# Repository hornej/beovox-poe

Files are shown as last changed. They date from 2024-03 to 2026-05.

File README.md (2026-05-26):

# BeoVox PoE

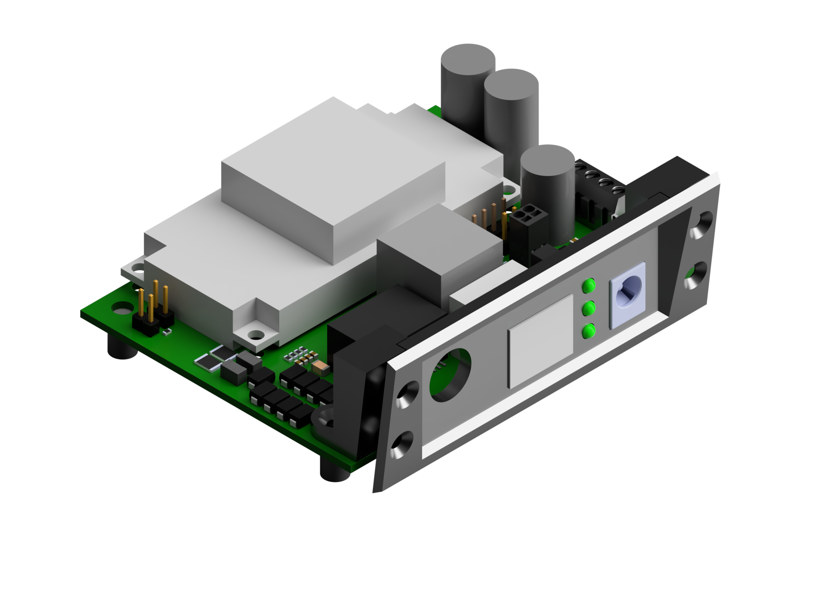
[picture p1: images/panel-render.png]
Panel mount render


BeoVox PoE is an 80 W PoE-PD power board and panel-mount system for installing a Raspberry Pi and a [HiFiBerry Beocreate amplifier](https://www.hifiberry.com/shop/boards/beocreate-4-channel-amplifier/) inside Bang & Olufsen BeoVox CX50 or CX100 speakers.

The design takes in PoE power, passes Ethernet data through to the Raspberry Pi, and gives you a single-cable install for a network-connected speaker build. HiFiBerryOS supports streaming music via Bluetooth, Airplay, Spotify, Roon, and more. 
## Table of Contents

- [Features](#features)
- [Repository Layout](#repository-layout)
- [Guides](#guides)
- [Photos](#photos)
- [Parts List](#parts-list)
- [PCB](#pcb)
  - [PCB Specs and Ordering](#pcb-specs-and-ordering)
  - [PCB Setup and Notes](#pcb-setup-and-notes)
  - [Soldering](#soldering)
  - [Jumper Headers](#jumper-headers)
  - [Optional Connections](#optional-connections)
- [Panel Mount](#panel-mount)
  - [3D Printing](#3d-printing)
  - [Rear Panel Opening](#rear-panel-opening)
  - [Panel Assembly](#panel-assembly)
- [Wiring](#wiring)
  - [CX50](#cx50)
  - [CX100](#cx100)
  - [CX100 with switchable subwoofer](#cx100-with-switchable-subwoofer)
- [Software Setup](#software-setup)
- [Future Work / Ideas](#future-work--ideas)
- [License](#license)

## Features

- 80 W 802.3bt / PoE++ speaker retrofit
- Powers the HiFiBerry Beocreate 4-channel amplifier
- Multi-room audio streaming via Airplay
- Ethernet passthrough for the Raspberry Pi
- 3D-printable panel and PCB mounting hardware
- Support for BeoVox Cona Subwoofer
- PCB can be used as a general purpose PoE++ power supply 

## Repository Layout

- [3d-files/](3d-files/)
  - CX100 retrofit panel and PCB mount files, including [CX100-panel.step](3d-files/CX100-panel.step), [CX100-panel-dcled.step](3d-files/CX100-panel-dcled.step), and [CX100-pcb-mounts.step](3d-files/CX100-pcb-mounts.step)
  - CX50 retrofit panel and PCB mount files, including [CX50-panel.3mf](3d-files/CX50-panel.3mf), [CX50-panel-dcled.step](3d-files/CX50-panel-dcled.step), and [CX50-pcb-mounts.step](3d-files/CX50-pcb-mounts.step)
  - Optional CX100 subwoofer panel files, amp cradle files, and connector models are also included in [3d-files/](3d-files/)
  - [hifiberry/](3d-files/hifiberry/) contains reference HiFiBerry models and related print files, including [hifiberry-beocreate-4-1.0.2.step](3d-files/hifiberry/hifiberry-beocreate-4-1.0.2.step), [recreate-cx-4ca-cradle-v3.stl](3d-files/hifiberry/recreate-cx-4ca-cradle-v3.stl), and [recreate-cx-plug.stl](3d-files/hifiberry/recreate-cx-plug.stl)
- [guides/](guides/)
  - Supporting build documentation index in [guides/README.md](guides/README.md)
  - Auxiliary guides, including [repairing-speakers/](guides/repairing-speakers/) and [diy-mini-xlr-cable/](guides/diy-mini-xlr-cable/)
- [images/](images/)
  - Build photos, CAD renders, board renders, and wiring diagrams used throughout this README
- [pcb-files/](pcb-files/)
  - Main Altium source files: [beovox-poe.PrjPcb](pcb-files/beovox-poe.PrjPcb), [beovox-poe.SchDoc](pcb-files/beovox-poe.SchDoc), [beovox-poe.PcbDoc](pcb-files/beovox-poe.PcbDoc), [beovox-poe.OutJob](pcb-files/beovox-poe.OutJob), [beovox-poe.IntLib](pcb-files/beovox-poe.IntLib), and [beovox-poe.LibPkg](pcb-files/beovox-poe.LibPkg)
  - Zipped Gerber files for PCB fabrication: [beovox-poe-v2.1-mfg.zip](pcb-files/beovox-poe-v2.1-mfg.zip)
  - Exported manufacturing outputs: [BOM/](<pcb-files/Project Outputs for beovox-poe/BOM/>), [Pick Place/](<pcb-files/Project Outputs for beovox-poe/Pick Place/>), [Gerber/](<pcb-files/Project Outputs for beovox-poe/Gerber/>), [NC Drill/](<pcb-files/Project Outputs for beovox-poe/NC Drill/>), and [ExportSTEP/](<pcb-files/Project Outputs for beovox-poe/ExportSTEP/>)
  - Reference PDFs: [beovox-poe_FabDwg.PDF](<pcb-files/Project Outputs for beovox-poe/beovox-poe_FabDwg.PDF>) and [beovox-poe_Schematic.PDF](<pcb-files/Project Outputs for beovox-poe/beovox-poe_Schematic.PDF>)
- [settings-backup.tar.gz](settings-backup.tar.gz)
  - HiFiBerryOS backup with the CX100 + Cona Subwoofer crossover, channel mapping, and output settings. Only use this if using the Subwoofer, HiFiBerryOS already includes the profiles for CX50, CX100, and others. 

## Guides

The root README focuses on the core build. Auxiliary information lives under [guides/](guides/):

- [Repairing speakers](guides/repairing-speakers/) for surrounds, replacement frames, and cloth sources
- [DIY Mini-XLR cable](guides/diy-mini-xlr-cable/) if HiFiBerry cables are unavailable

## Photos

Front view
Rear view

## Videos

[BeoVox PoE Demo - CX100](https://youtu.be/9oT_c17GFdE)

[BoeVox PoE Assembly - CX50](https://youtu.be/0kofoiOvvGE)

[BeoVox PoE Assembly - CX50 (10x speed)](https://youtu.be/bw3L32bcnUU)

## Parts List

| Name | Description | Link | Cost |
| --- | --- | --- | --- |
| **PCB + Electronics** | | | |
| BEOVOX-POE PCB fabrication + assembly | Fabricated PCB with top-side assembly from JLCPCB using the exported BOM and pick-and-place files. | https://jlcpcb.com/ | You should be able to get 2-5 units assembled for around ~$100 |
| Silvertel AG5800 | IEEE 802.3bt 4-pair PD module; hand-soldered after PCB assembly. | [Silvertel AG5800](https://www.digikey.com/en/products/detail/silvertel/AG5800/21187212) | $24.97 |
| YIYUAN SMTSOM380BTR or Keystone 24885 | M3 threaded insert / nut option used on the board. Non-soldered standoffs or nuts can also be used. | [YIYUAN SMTSOM380BTR](https://www.lcsc.com/product-detail/SMD-round-nut_YIYUAN-SMTSOM380BTR_C5301772.html)<br>[Keystone 24885](https://www.digikey.com/en/products/detail/keystone-electronics/24885/9921825) | ~$1 |
| **3 pcs** 100mil jumpers | These are used to select the PD signature options | [M254D-02-065-B](https://www.lcsc.com/product-detail/C2998928.html) You can find these at DigiKey, Amazon, LCSC, etc | $0.44 |
| | | | |
| **Speakers + Amp** | | | |
| Pair of BeoVox CX50 or CX100 speakers | | I found my CX50 on eBay for $123 including shipping and CX100 for $236. | $100-$250 |
| HiFiBerry Beocreate 4 Channel Amplifier | 4 Channel Amplifier up to 180W | [HiFiBerry Beocreate 4 Channel Amplifier](https://www.hifiberry.com/shop/bundles/beocreate-bundle/) | $199.00 |
| Raspberry Pi 4B/1GB | You can use a Raspberry Pi 5 or get more RAM if you want, but its not necessary. Small adhesive heatsinks are not a bad idea. | [Raspberry Pi 4 Model B/1GB](https://www.pishop.us/product/raspberry-pi-4-model-b-1gb/?src=raspberrypi) | $35 |
| Micro SD Card | Class 10 at least 8GB | | ~$10 |
| (Optional) BeoVox Cona Subwoofer | | I bought mine used on eBay | $250-$500 |
| (Optional) HiFiBerry 20V/80W Power Supply | Only needed if you are not going to power with PoE. | [HiFiBerry 20V/80W Power Supply](https://www.hifiberry.com/shop/accessories/power-20v-80w/) | $32.90 |
| | | | |
| **Other** | | | |
| **4 pcs** M3 x 4 mm (5mm OD) threaded inserts | Inserts for the printed PCB mount parts. | [Assorted Threaded Inserts](https://a.co/d/07zoHJ45) | $15.98 |
| **6 pcs** M3 x 8 mm flat-head screws | Screws for fastening the PCB to the printed mounts | [Assorted Hex Screws](https://a.co/d/05N6zpqh) | $12.99 |
| Wire | Wire for routing power and speakers internally. ~20-22AWG wire should work | | |
| CAT6 jumper cable 1.5ft | Network and PoE cabling | https://a.co/d/05UuwCxJ | $12.99 |
| IEEE 802.3bt / PoE++ switch or injector | | I have this injector from LCSC [WC-PSE90B01](https://www.lcsc.com/product-detail/C2848011.html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) | |
| 3D printer filament | Filament for the panel and PCB mount prints | [Overture Matte White PLA](https://a.co/d/0gjsfJBm) | $16.99 |
| Thermal interface material | Use to interface AG5800 to PCB | | |
| **2 pcs** HiFiBerry Mini-XLR plug 4 pin (female) | | [HiFiBerry Mini-XLR plug 4 pin (female)](https://www.hifiberry.com/shop/accessories/mini-xlr-plug-4-pin-female/) | $5.80 |
| HiFiBerry Mini-XLR cable 4 pin (female/female) | You can also make this cable yourself. See the [DIY Mini-XLR cable guide](guides/diy-mini-xlr-cable/). | [HiFiBerry Mini-XLR cable 4 pin (female/female)](https://www.hifiberry.com/shop/accessories/mini-xlr-cable-4-pin-female-female/) | $14.90 |
| Beovox CX50/CX100 3D parts | These are cheaper if you buy the amp bundle. Or you can 3D print yourself (see [3d-files/](3d-files/)) | [Beovox CX50/CX100 3D parts](https://www.hifiberry.com/shop/beocreate/beovox-3dparts/) | $9.90 |
| (Optional) (2pcs) 5mm Thermal pad | You could use two pieces of thermal pad to interface the bottom of the PCB to the speaker cabinet for better thermal dissipation | | |

## PCB

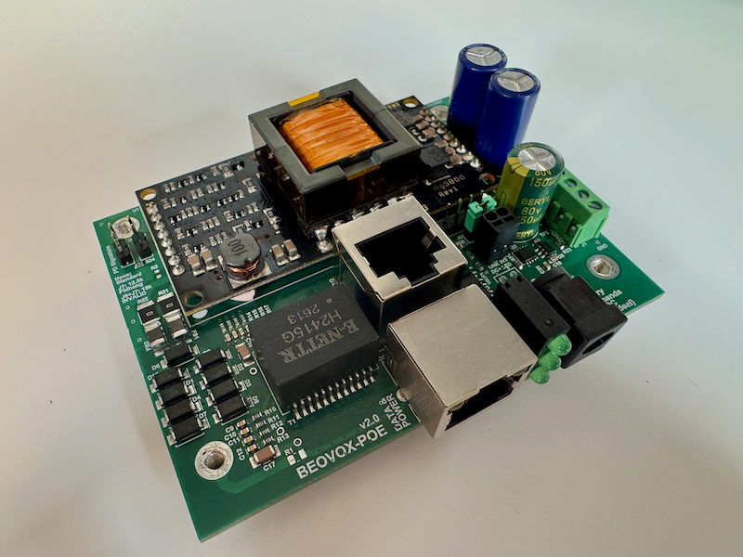
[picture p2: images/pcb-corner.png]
PCB

### PCB Specs and Ordering
This design was prepared to be fabricated and assembled by [JLCPCB](https://jlcpcb.com/). 

The PCB is available [here](https://oshwlab.com/hornej/project_ngqmoynx) on OSHWLab where you can order from JLCPCB's free EDA tool, EasyEDA. You can also find the Altium source files in the repo in [pcb-files](pcb-files). 

These are the lowest cost specs
- Stackup: JLC04161H-7628. 1oz outer copper, 1/2oz inner copper
	- I designed the Ethernet traces to 100 ohm differential for this stackup. If you want guaranteed impedance control you can select that for an extra cost.
	- It wouldn't hurt to use thicker copper but I think 1oz outer, 1/2oz inner is fine. 
- Green soldermask, White overlay
	- You can get whatever color you want, but green is the cheapest. 
- HASL
- Economy assembly (top side)
	- JLCPCB does not stock the Silvertel AG5800 module so that needs to be sourced separately and hand-soldered. The M3 standoffs on the bottom of the PCB also need to soldered, or can be swapped for non-soldered standoffs or nuts. 
### PCB Setup and Notes
For full output power you will need a IEEE 802.3bt / PoE++ source. I've also tested using a PoE+ source with success. You mileage may vary depending on how hard you are driving the speakers. 

### Soldering
- Solder the AG5800 module
- Solder the standoffs on the bottom
- Solder the 24V jumper on the bottom<br />
  24V jumper location
### Jumper Headers
- Leave J6 and J7 jumpers uninstalled
- If you are using a PoE switch for data but want to power the speakers with a DC power supply via the barrel jack then you can install a jumper on J2. When the barrel jack is present, the AG5800 POE-PD signature will be set to invalid. This will prevent the AG5800 from requesting power and will save on idle power dissipation. 
### Optional Connections
- (Optional) DC jack power LED through hole pads. You can solder an LED to these two pins to attach a panel mount LED. 
- (Optional) Raspberry Pi Link Status
	- If you want to see the Ethernet link status on the panel RJ45 jack then you need to connect to these pins on the RPi. Red is for 3.3V and Green is the LED. 
	- The PCB has a 2 pin push in terminal to attach this wires to. You will need to tin the wires before insertion into the terminal. 

  Raspberry Pi link status wiring

## Panel Mount
Separate panel files are provided for CX50 and CX100 cabinets because the rear-panel geometry is different.
### 3D Printing
For CX100, print `3d-files/CX100-panel.step` or `3d-files/CX100-panel-dcled.step`, plus `3d-files/CX100-pcb-mounts.step`.

For CX50, print `3d-files/CX50-panel.3mf` or `3d-files/CX50-panel-dcled.step`, plus `3d-files/CX50-pcb-mounts.step`.

Optional printable parts include the CX100 subwoofer panel variants, `3d-files/amp-cradle.step`, `3d-files/dc-barrel-plug.step`, and the `3d-files/mini-xlr-plug-*.step` models.
### Rear Panel Opening
The safest way to make the speaker cutout is to print the panel first and use the actual printed part as the template. That accounts for cabinet variation, printer tolerance, and any cleanup you do on the finished print. 
1. Print your chosen CX50 or CX100 panel file before you touch the speaker cabinet.
2. Pick the mounting location on the rear of the cabinet and make sure there is clearance inside for the RJ45 jacks, barrel jack, and PCB assembly. 
3. Put painter's tape over the cut area, mark your centerlines, and trace around the rear insertion lip of the printed panel. Do not trace the front flange; the flange is supposed to overlap the hole. 
4. Drill a starter hole near each corner, staying just inside the traced line. 
5. Connect the holes with a rotary tool, coping saw, jigsaw, or whatever small cutting tool you trust for the cabinet material. 
6. Finish with a hand file. It is easier to remove a little more material than it is to repair an oversized opening. 
### Panel Assembly
1. Fasten the printed mounts to the PCB with the flat-head screws.
## Wiring
The Amplifier fits best in the top section at a downward angle with the PoE PCB being at the bottom. 

Internal assembly

*CX100 wiring (no sub)*

### CX50
[HiFiBerry CX50 Installation Guide](https://github.com/bang-olufsen/create/blob/master/Guides/Upcycle%20CX50%20Stereo.pdf)
CX50 wiring diagram
### CX100
[HiFiBerry CX100 Installation Guide](https://github.com/bang-olufsen/create/blob/master/Guides/Upcycle%20CX100%20Stereo.pdf)
CX100 wiring diagram
### CX100 with switchable subwoofer
CX100 with switchable subwoofer wiring diagram
The subwoofer wiring is a little tricky. I underestimated how many wires I would need to reroute the standard stereo wiring to the subwoofer. I used two 4PDT [switches](https://www.digikey.com/en/products/detail/nkk-switches/M2042E2S1W01/1049104). 

Subwoofer switch panel

## Software Setup
Do this before you put it all back together!
- Download latest 64bit release of [HiFiBerryOS](https://github.com/hifiberry/hifiberry-os)
- Use [Raspberry Pi Imager](https://www.raspberrypi.com/software/) (or your preferred software) to install the OS on your microSD card
- Install the Raspberry Pi on the amplifier and power on. You can connect to a screen and keyboard/mouse but I would recommend using an Ethernet cable and set up via a browser. Once the Pi is on the network you can then set it up by going to your browser and entering its IP address. 
- Follow the guided setup to choose your speaker profile and other settings.
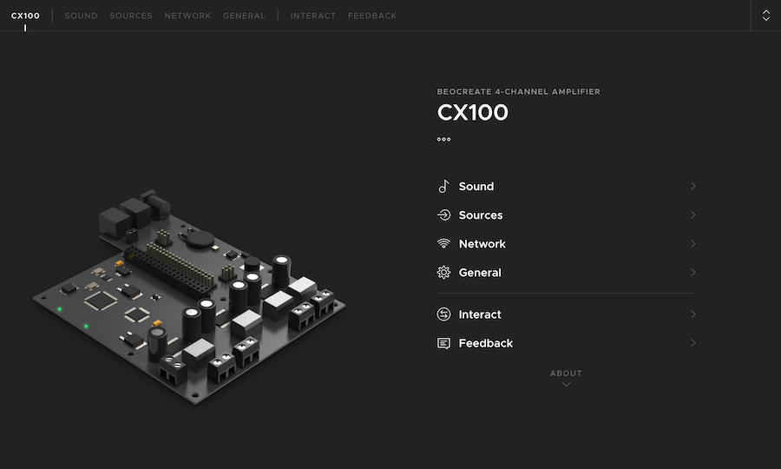
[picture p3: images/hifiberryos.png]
HiFiBerryOS setup screen

If you are using a BeoVox Cona Subwoofer, you can restore my [settings-backup.tar.gz](settings-backup.tar.gz), which contains the specific crossover and output settings I use. General -> System Tools -> Restore.

## Future Work / Ideas

- Simplify subwoofer wiring with external speaker crossover PCB with relays
- USB-C PD variant
- I2C temp sensor for the Pi to monitor the internal temperature
- NFC phone handoff (similar to Apple HomePod)
- Physical media controls
- External standalone enclosure to use the amplifier with other speakers
## License

This repository is distributed under the [MIT License](LICENSE).

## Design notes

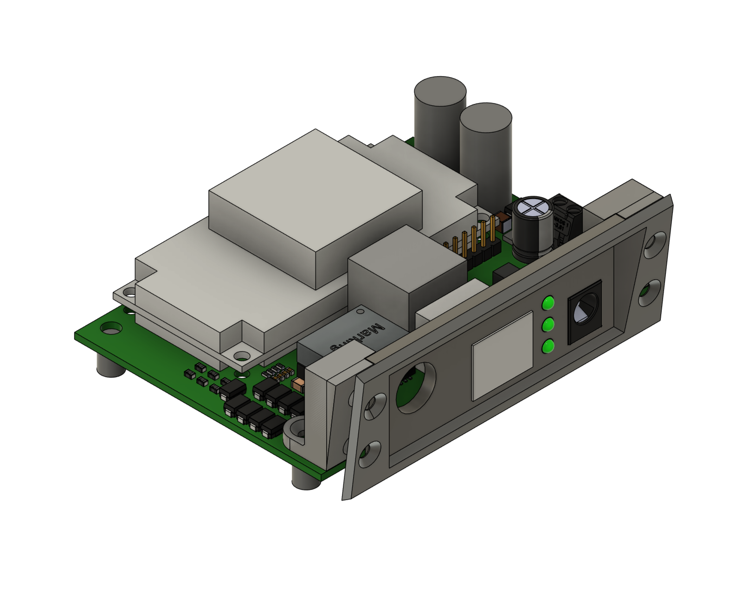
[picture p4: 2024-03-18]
images/beovox-panel-mount-fusion.png

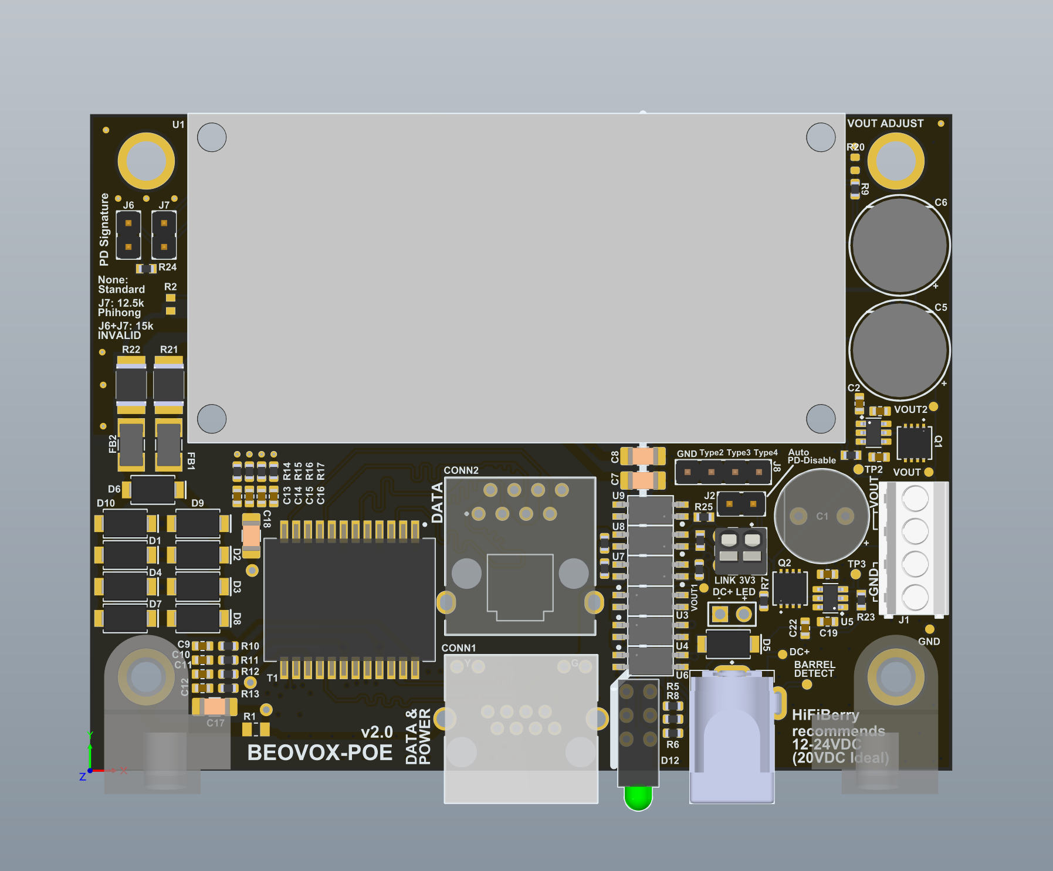
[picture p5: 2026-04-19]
images/pcb-top-view.png

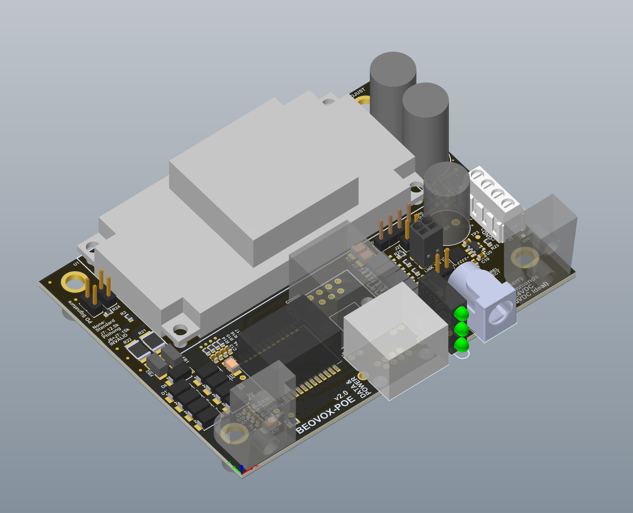
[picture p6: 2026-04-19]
images/pcba-v2.0a.png

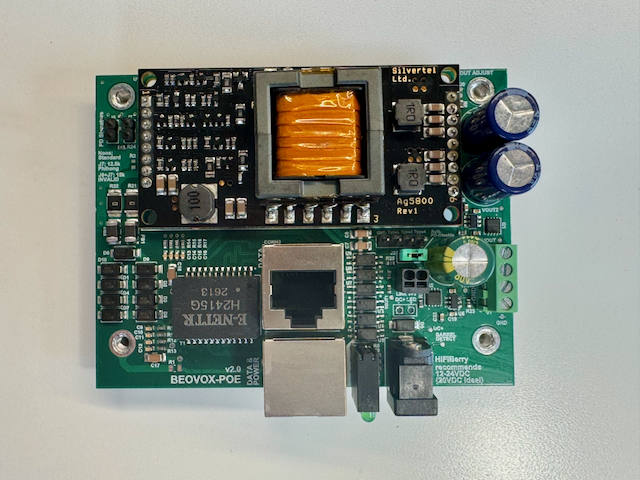
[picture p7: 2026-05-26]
images/pcb-top.png

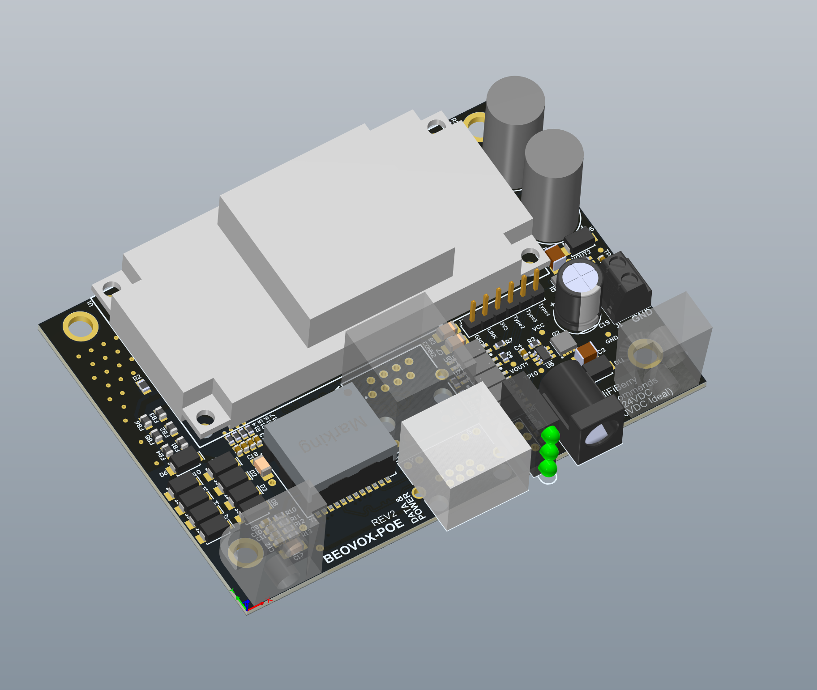
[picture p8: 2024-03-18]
images/pcb.png

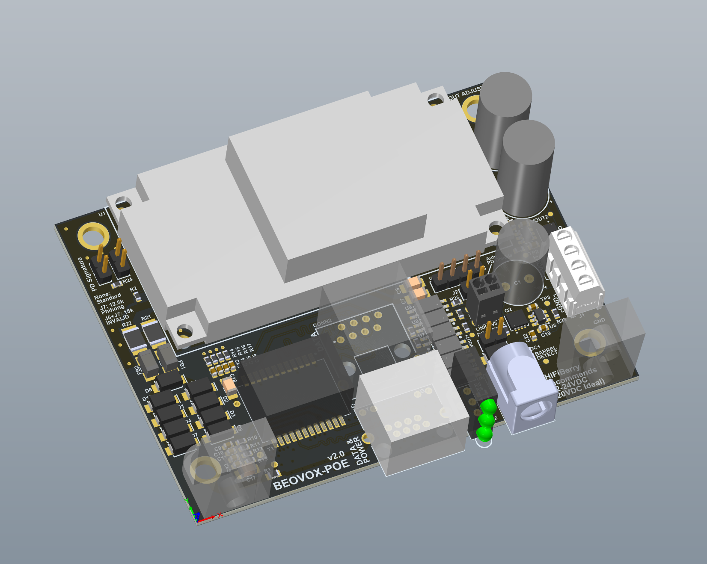
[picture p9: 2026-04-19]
images/pcba-v2.0.png

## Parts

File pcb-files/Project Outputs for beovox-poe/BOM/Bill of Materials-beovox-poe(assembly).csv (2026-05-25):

Designator | Quantity | Supplier | Supplier Part Number | Manufacturer | Manufacturer Part Number | Comment | Footprint | Description | Case/Package
C1 | 1 | LCSC | C7436420 | BERYL Electronic Tech | RC080M151LO10*16TH-2A1Et | 150uF | CAP_CAN_10D_16H_THT | 150uF 80V Aluminum Electrolytic Capacitors Through Hole,D10xL16mm 3000hrs@105?
C2, C4, C19, C20, C21, C22 | 6 | LCSC | C14663 | Yageo | CC0603KRX7R9BB104 | 100nF | CAP_0603_SK | Multilayer Ceramic Capacitor, CC Series, 0.1 - F, - 10%, X7R, 50 V, 0603 [1608 Metric] | 0603
C5, C6 | 2 | LCSC | C398835 | AISHI | ERR1VM102G20OT | 1000uF 35V | CAP_TH_5_10X20 | 1000uF 35V ±20% Plugin,D10xL20mm Aluminum Electrolytic Capacitors - Leaded ROHS
C7, C8 | 2 | LCSC | C41017 | FH (Guangdong Fenghua Advanced Tech) | 1206B472K202NT | 4.7nF 2kV | CAP_1206_SK | 2kV 4700pF X7R ±10% 1206 Multilayer Ceramic Capacitors MLCC - SMD/SMT ROHS
C9, C10, C11, C12, C13, C14, C15, C16 | 8 | LCSC | C302008 | Walsin Technologies | 0603B103K101CT | 10nF | CAP_0603_SK | Multilayer Ceramic Capacitor, 0.01 F, 10%, X7R, 100 V, 0603 [1608 Metric] Rohs Compliant: Yes | 0603
C17, C18 | 2 | LCSC | C23631 | Yageo | CC1206KKX7RDBB102 | 1000pF 2kV | CAP_1206_SK | Multilayer Ceramic Capacitor, 1000 pF, 2000 V, ± 10%, X7R, 1206 [3216 Metric] | 1206
CONN1 | 1 | LCSC | C386757 | Ckmtw | R-RJ45R08P-C000 | R-RJ45R08P-C000 | R-RJ45R08P-C000 | RJ45 RJReceptacle 1 ??? Right-Angle WithLED 0?~+70? Plugin Ethernet Connectors/Modular Connectors (RJ45 RJ11) ROHS
CONN2 | 1 | LCSC | C2683357 | Kinghelm | KH-5224-8P8C | KH-5224-8P8C | CONN_RJ45_KH-5224-8P8C | Jack Modular Connector RJ45 Through Hole Shielded
CONN3 | 1 | LCSC | C3096089 | Same Sky | PJ-050AH | PJ-050AH | CUI_PJ-050AH | 2.0 x 6.0 mm, 5.0 A, Horizontal, Through Hole, Pick-n-Place Top, Dc Power Jack Connector
D1, D2, D3, D4, D7, D8, D9, D10 | 8 | LCSC | C16015 | MDD | SS36 | SS36 | DIOD-SMA-2_V | 60V 700mV@3A 3A SMA(DO-214AC) Schottky Barrier Diodes (SBD) ROHS
D5 | 1 | LCSC | C148230 | Littelfuse | SMAJ30A | SMAJ30A | DIOD-B360A_V | Diode TVS Single Uni-Dir 30V 400W 2-Pin SMA | SMA
D6 | 1 | LCSC | C2980408 | GOODWORK | SMAJ58A | SMAJ58A | DIOD-SMA-2_V | 4.3A 400W 93.6V 64.4V 58V SMA(DO-214AC) TVS ROHS
D12 | 1 | LCSC | C7470849 | MEIHUA | MHK33147CGBTD | 3 Diode Vertical LED Green | MHK33147CGBTD | 20mA 30mcd ????? -40?~+85? 568nm Green 60° 2.6V DIP-6-2.54mm Light Emitting Diodes (LED) ROHS
FB1, FB2 | 2 | LCSC | C515372 | TAIYO YUDEN | FBMH4525HM102NTV | 1k | FB_1810 | Ind Chip Bead Multi-Layer 1KOhm 30% 100MHz Ferrite 3A 1810 T/R | 1810
J1 | 1 | LCSC | C2757925 | DIBO | DB125-3.5-4P-GN-S | DB125-3.5-4P-GN-S | DB125-3.5-4P-GN-S | 1x4P -40?~+105? 13.5A 250V Green 16~28 Straight pin 3.5mm 1 1 4 Plugin,P=3.5mm Screw terminal ROHS
J2, J6, J7 | 3 | LCSC | C492401 | XFCN | PZ254V-11-02P | PZ254V-11-02P | 61300211121 | Straight Square Pins 2.5mm 6mm -40?~+105? 1 3mm 2 2.54mm Black Brass 1x2P Plugin,P=2.54mm Pin Headers ROHS
J8 | 1 | LCSC | C2691448 | XFCN | PZ254V-11-04P | PZ254V-11-04P | HDR_MALE_1x4 | 250V 3A Straight Square Pins 2.5mm 4P 6mm -40?~+105? 3mm 2.54mm Plugin Black 1x4P Plugin,P=2.54mm Pin Headers ROHS
J9 | 1 | LCSC | C3817232 | Phoenix Contact | 1770953 | 1770953 | 1770953 | TERM BLK 2P TOP ENTRY 2.5MM PCB
MP1, MP2, MP3, MP4 | 4 | LCSC | C5301772 | YIYUAN | SMTSOM380BTR | SMTSOM380BTR | SMTSOM380_PlatedScrew | M3 Round Nut 8mm height
Q1, Q2 | 2 | LCSC | HSBB6066 | HUASHUO | HSBB6066 | HSBB6066 | PPAK3X3_GAS | N-Channel 60V 60A 45W PRPAK3x3-8L
R3, R23 | 2 | LCSC | C21189 | Royal Ohm | 0603WAF0000T5E | 0 | RES_0603 | Thick Film Resistors - SMD RMC 0603 1/10W 1% T/R-5000
R4, R5, R6, R8, R25 | 5 | LCSC | C4190 | Royal Ohm | 0603WAF2201T5E | 2.2k | RES_0603 | Res Thick Film 0603 2.2K Ohm 1% 0.1W(1/10W) ±100ppm/C Pad SMD T/R
R7, R18, R19, R24 | 4 | LCSC | C25804 | Royal Ohm | 0603WAF1002T5E | 10k | RES_0603 | Res Thick Film 0603 10K Ohm 1% 0.1W(1/10W) ±100ppm/C Pad SMD
R9 | 1 | LCSC | C137671 | Yageo | RC0603FR-0791KL | 91k | RES_0603 | SMD Chip Resistor, 91 kOhm, ± 1%, 100 mW, 0603 [1608 Metric], Thick Film, General Purpose | 0603
R10, R11, R12, R13, R14, R15, R16, R17 | 8 | LCSC | C112309 | Yageo | RC0603FR-0775RL | 75 | RES_0603 | SMD Chip Resistor, 75 Ohm, ± 1%, 100 mW, 0603 [1608 Metric], Thick Film, General Purpose | 0603
R21, R22 | 2 | LCSC | C2999613 | FOJAN | FRC1812F0000TS | 0 | RES_1812 | -55?~+155? 0O 1W 200V Thick Film Resistor ±5% 1812 Chip Resistor - Surface Mount ROHS
R26 | 1 | LCSC | C23138 | Royal Ohm | 0603WAF3300T5E | 330 | RES_0603 | Fixed Resistor, Metal Glaze/thick Film, 0.1W, 330ohm, 75V, 1% +/-Tol, 100ppm/Cel, Surface Mount, 0603
T1 | 1 | LCSC | H2415G | E-NETTR | H2415G | H2415G | XFMR_H2415G | LAN Transformer 1:1 Surface Mount IEEE 802.3bt
U1 | 1 |  |  | Silvertel | AG5800 | AG5800 | AG5800 | IEEE802.3bt 4-Pair PD Module - works with AG6800
U2, U5 | 2 | LCSC | C2653623 | Texas Instruments | LM74700QDBVTQ1 | LM74700QDBVTQ1 | SOT95P280X145-6N | Low IQ Reverse Battery Protection Ideal Diode Controller 3.2V to 65V 6-Pin SOT-23 T/R | SOT-23-6
U3, U4, U6, U7, U8, U9 | 6 | LCSC | C282477 | Orient | OR-3H7B-TP-G | OR-3H7B-TP-G | SOIC_(B)(TA)-VG_EVS | 80V 3750V 50mA 0.4V@2.4mA,8mA 1 6V 1.2V DC SOP-4-1.27mm Optocouplers - Phototransistor Output ROHS

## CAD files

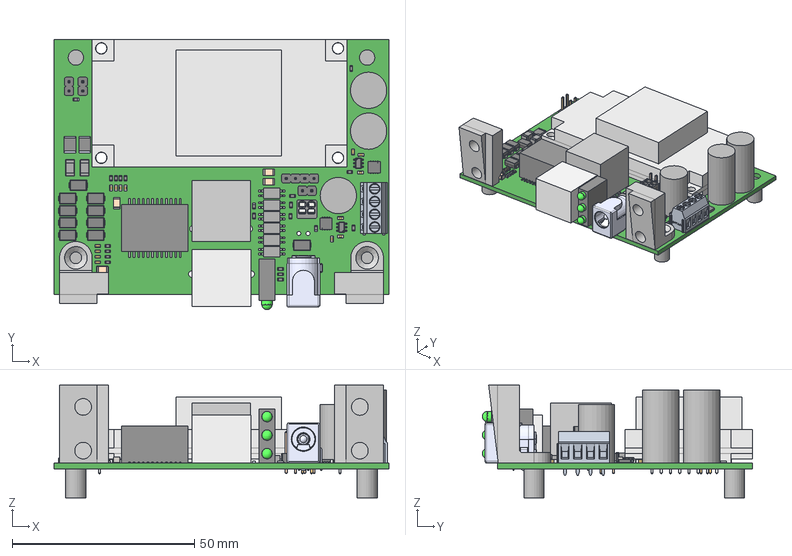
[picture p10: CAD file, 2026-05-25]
pcb-files/Project Outputs for beovox-poe/ExportSTEP/beovox-poe(assembly).step
92.0 x 74.3 x 31.0 mm
Extruded x 28
6130xx11121_PIN x 10
SOIC__B__TA_-VG_EVS x 6
ESR03EZPJ101 x 21
User_Library-CAPC1608X09 x 14
LM74700QDBVTQ1 x 2
db125-35-4p-s
Open_CASCADE_STEP_translator_6.8_4.1.1
Lead x 20
ERJL12KF39MU x 2
User_Library-CAPC3216X___CAPC3216X180N x 4
Ag5800
FBMH4525HM102NTV_RGB6710886 x 2
Open_CASCADE_STEP_translator_6.8_6.1.1 x 9
Same_Sky_PJ-050AH
panel-right
panel-left

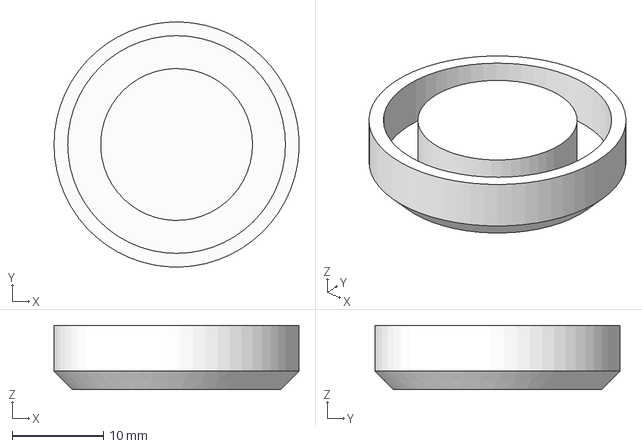
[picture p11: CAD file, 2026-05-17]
3d-files/dc-barrel-plug.step
26.8 x 26.8 x 7.00 mm

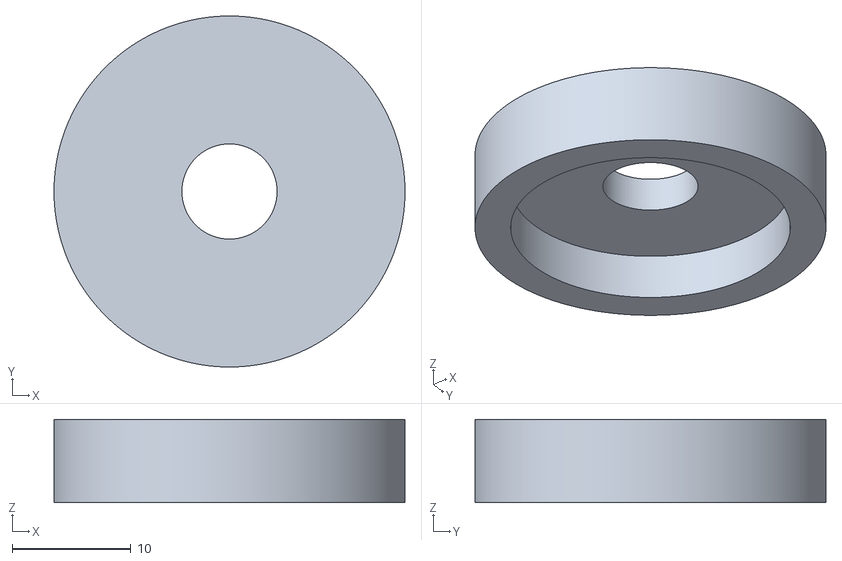
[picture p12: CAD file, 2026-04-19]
3d-files/hifiberry/recreate-cx-plug.stl
29.5 x 29.5 x 7.00

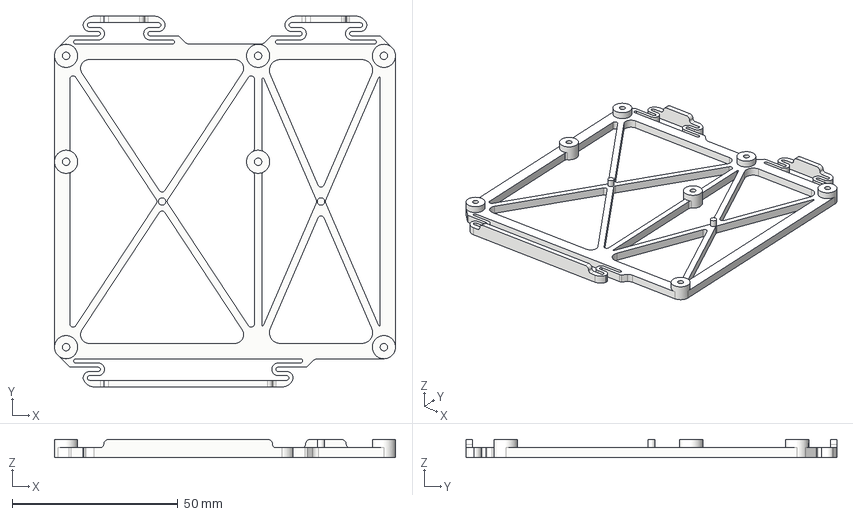
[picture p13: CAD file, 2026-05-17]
3d-files/amp-cradle.step
103.0 x 112.0 x 5.50 mm

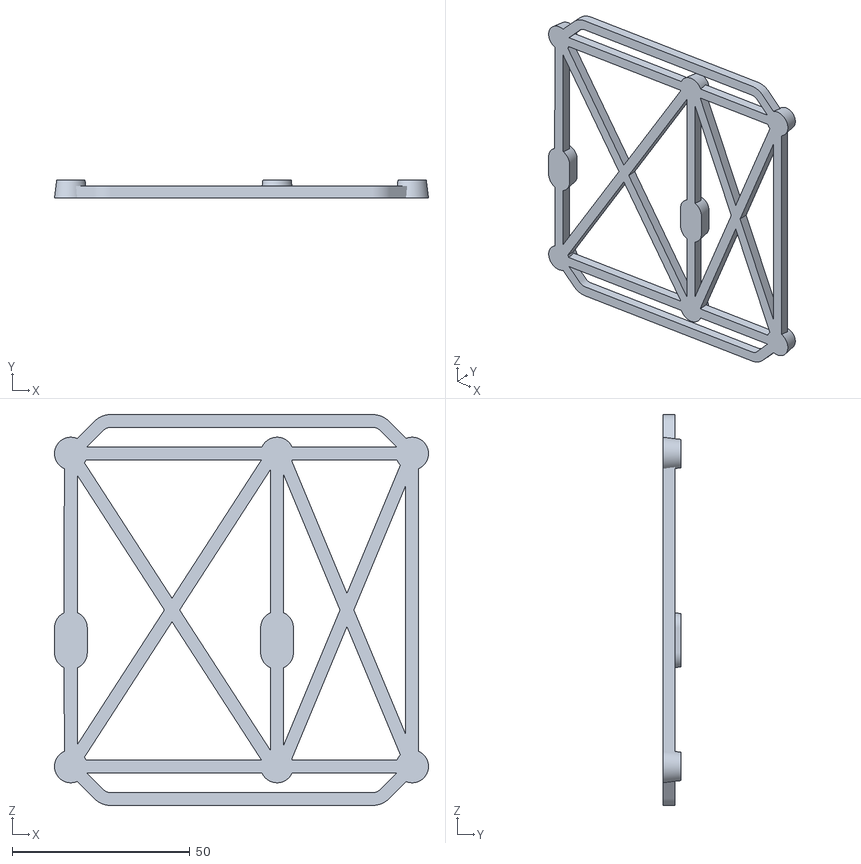
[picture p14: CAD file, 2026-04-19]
3d-files/hifiberry/recreate-cx-4ca-cradle-v3.stl
105.2 x 5.00 x 110.0

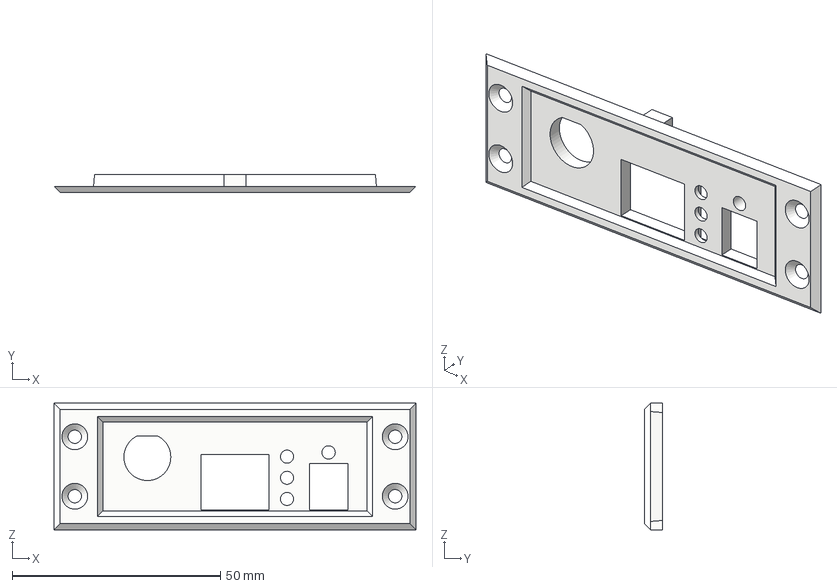
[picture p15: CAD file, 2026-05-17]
3d-files/CX50-panel-dcled.step
87.0 x 4.40 x 30.4 mm

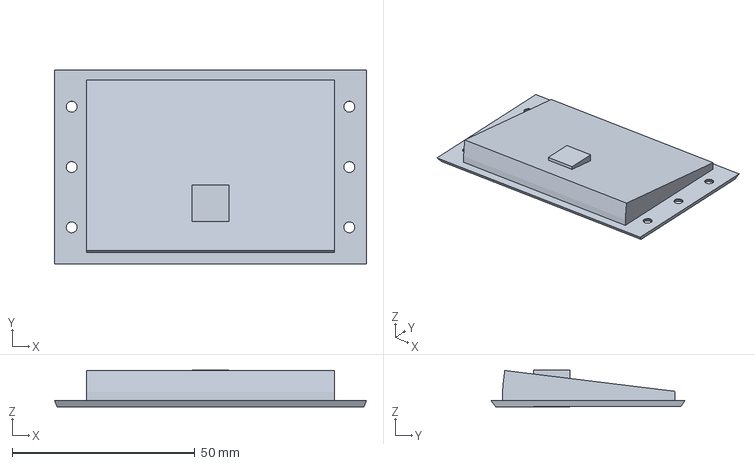
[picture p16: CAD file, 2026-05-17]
3d-files/CX100-panel-sub-mini-xlr.3mf
85.4 x 53.2 x 10.0 mm

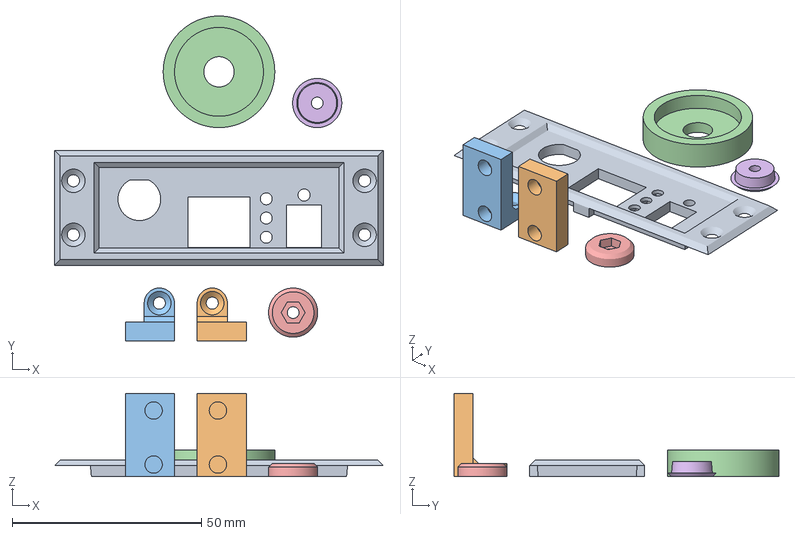
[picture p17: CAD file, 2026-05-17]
3d-files/CX50-panel.3mf
87.0 x 85.9 x 22.0 mm
panel2
beovox-panel-mounts-CX50_1
beovox-panel-mounts-CX50_2
recreate-cx-plug.stl
mini-xlr-plug-inner
mini-xlr-plug-outer

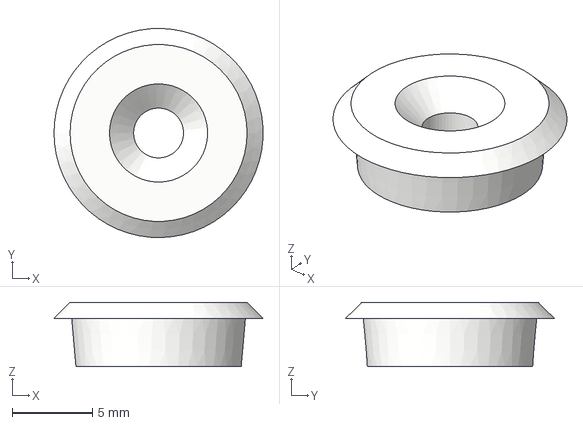
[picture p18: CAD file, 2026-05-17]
3d-files/mini-xlr-plug-outer.step
13.0 x 13.0 x 4.00 mm

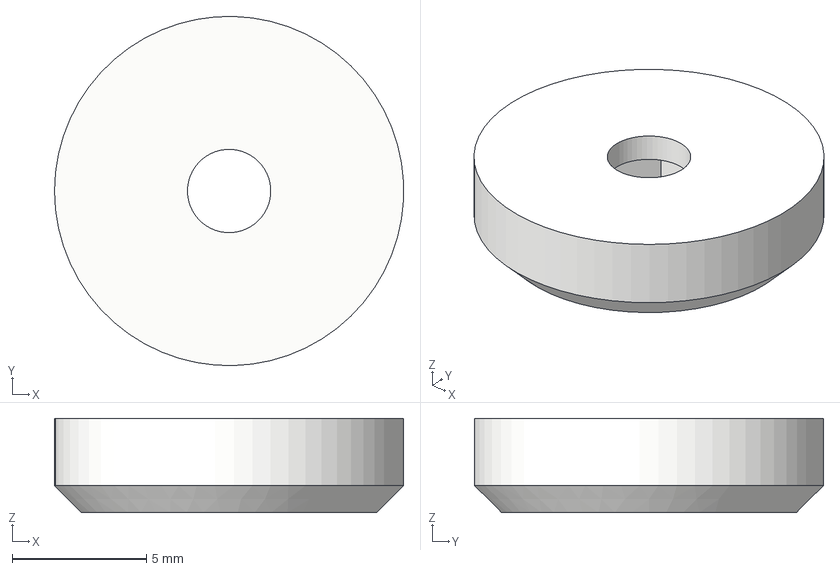
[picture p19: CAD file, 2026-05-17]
3d-files/mini-xlr-plug-inner.step
13.0 x 13.0 x 3.50 mm

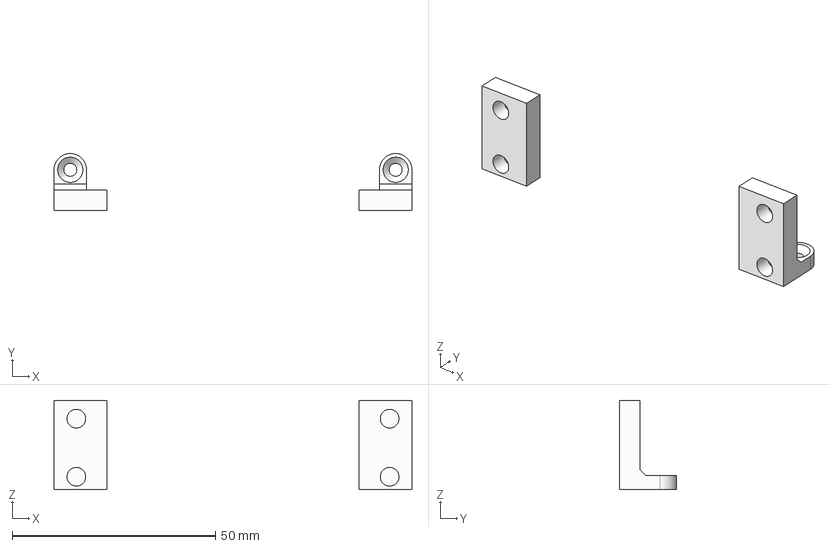
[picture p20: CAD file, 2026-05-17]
3d-files/CX50-pcb-mounts.step
88.0 x 14.0 x 22.0 mm

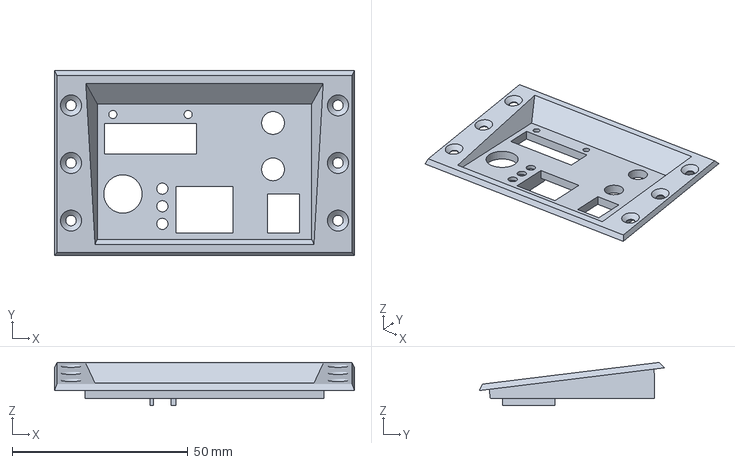
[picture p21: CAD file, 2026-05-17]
3d-files/CX100-panel-sub.3mf
85.4 x 52.8 x 12.3 mm

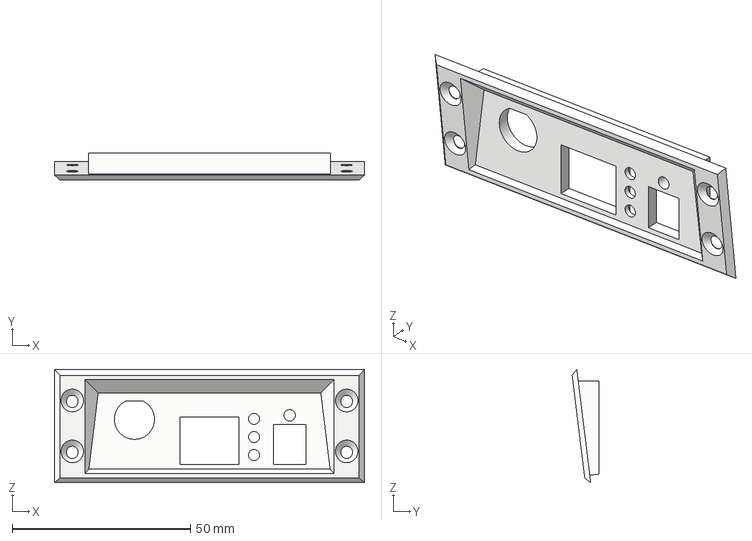
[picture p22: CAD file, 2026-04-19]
3d-files/CX100-panel-dcled.step
87.0 x 7.50 x 31.8 mm

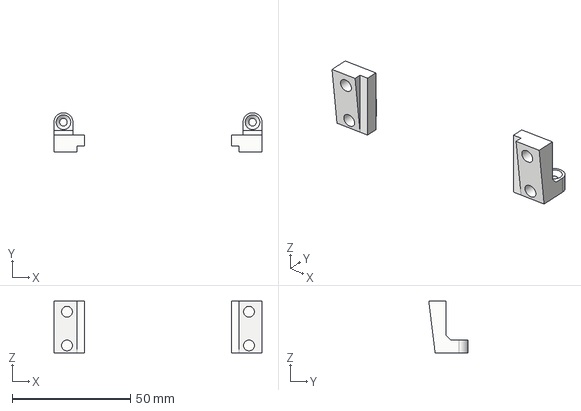
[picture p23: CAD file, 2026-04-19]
3d-files/CX100-pcb-mounts.step
88.0 x 16.7 x 22.0 mm

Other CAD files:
3d-files/CX100-panel-sub-blank.step
3d-files/CX100-panel.step
3d-files/CX100-panel-dcled.3mf
3d-files/CX100-panel-sub-blank.stl
3d-files/CX100-pcb-mounts.3mf
3d-files/amp-cradle.3mf
3d-files/dc-barrel-plug.3mf

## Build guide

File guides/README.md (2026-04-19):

# Guides

Auxiliary documentation that supports the BEOVOX-POE build but is not part of the core panel, PCB, or wiring workflow.

- [Repairing speakers](repairing-speakers/) for surrounds, frame replacement, and cloth resources
- [DIY Mini-XLR cable](diy-mini-xlr-cable/) if you need to make your own 4-pin cable

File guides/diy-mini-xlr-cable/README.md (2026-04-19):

# Making Your Own Mini-XLR Cable

When I was building this project, HiFiBerry did not have cables in stock so I had to make my own. Here is what you need.

## Materials

- [Mini-XLR 4pin plugs](https://a.co/d/05eEJEnN)
- [Canare L-4E5C Mini-Star-Quad Microphone Cable by the Foot](https://www.markertek.com/product/l-4e5c-bk/canare-l-4e5c-mini-star-quad-microphone-cable-by-the-foot-black)

## Plug Disassembly

Mini-XLR plug disassembled

1. Strip back the insulation, shielding and wires to appropriate length
2. Install the plug cover, plastic cover, and metal wire relief. **IMPORTANT. Do this before you solder both ends of the cable**
3. Tin the plug and wires with solder
4. Solder wires. Make sure wires are connected to same pin on the plug on each side
5. Screw on plug cover

Cable prep
Soldering detail 1
Soldering detail 2
Soldering detail 3
Finished connector

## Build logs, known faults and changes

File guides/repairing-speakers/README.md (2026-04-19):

# Repairing the Speakers

## Speaker Surrounds

- [HiFiBerry speaker refoaming guide](https://github.com/bang-olufsen/create/blob/master/Guides/Replace%20Speaker%20Foams.pdf)
- After trying several poor-fitting Amazon and eBay options, these are the best fitting surrounds I found for CX50 and CX100 speakers: [Audiofriends 4 AF 86B rubber surround](https://www.repairyourspeakers.com/en/surrounds-by-size/2-4-inch/4-af-86b-rubber-surround-for-repair-speaker/a-2640-10000068)
- [Audiofriends replacement video](https://youtu.be/A_NZoNgs02c?si=07Pem7QP0-d5mRjE)

## Speaker Frames and Cloth

- Printable replacement frames: [Thingiverse](https://www.thingiverse.com/thing:365459)
- Black speaker cloth: [Joann speaker cloth](https://www.joann.com/utility-fabric-black-speaker-cloth/3514023.html)
- Gray speaker cloth: [Parts Express speaker grill cloth](https://www.parts-express.com/Speaker-Grill-Cloth-Gray-Yard-70-Wide-260-337?quantity=1)

Replacement CX100 speaker frame

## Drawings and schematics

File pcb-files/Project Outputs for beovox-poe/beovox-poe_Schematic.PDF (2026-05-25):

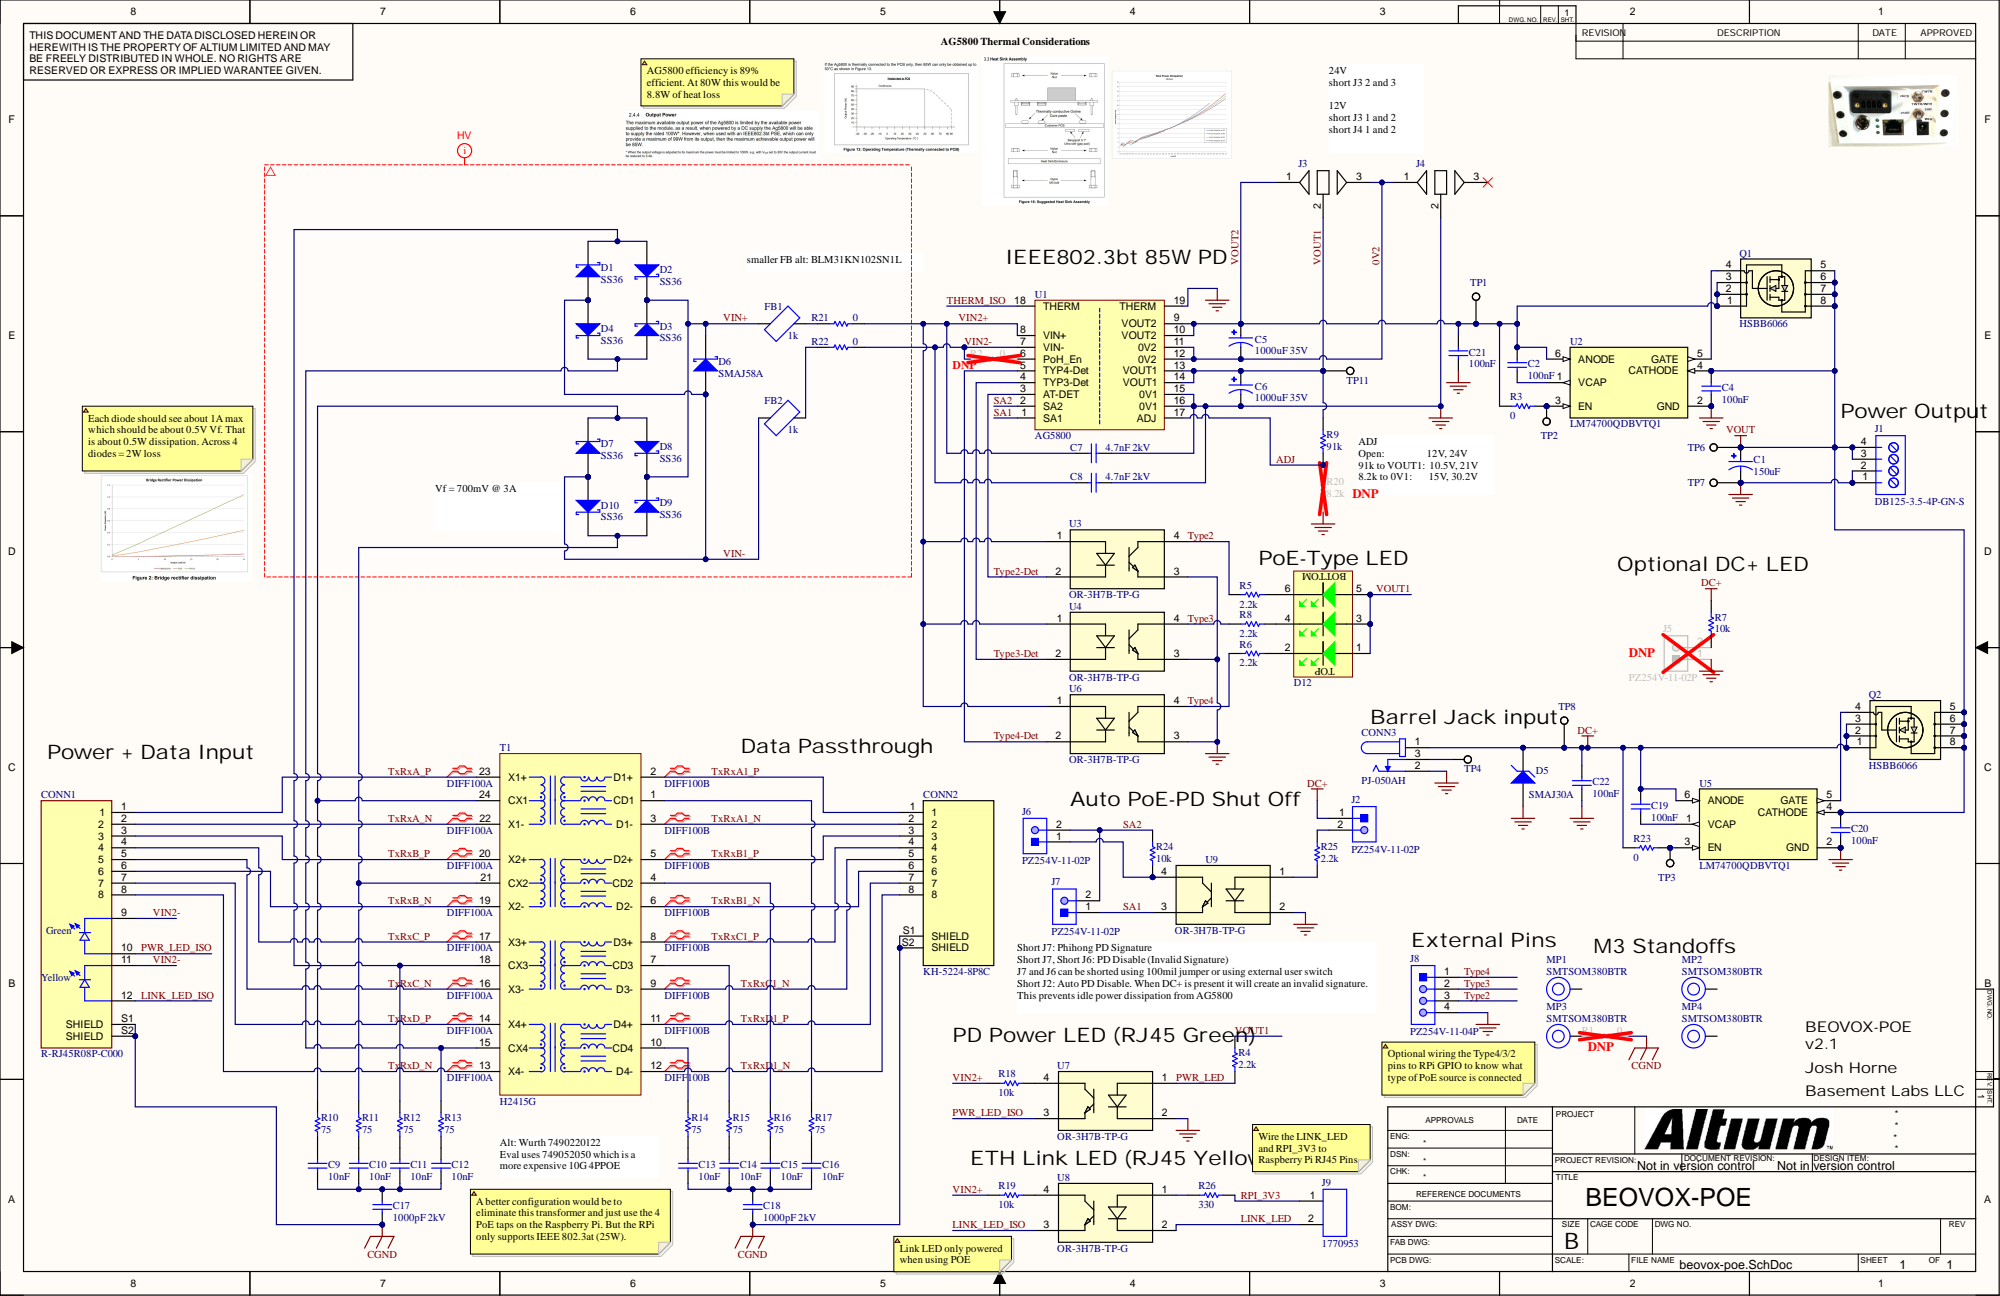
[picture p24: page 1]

DWG . N O . | R E V | 1 . S H T.

T H IS DOC U MEN T AN D T HE D ATA D ISCLOSED HEREI N OR HEREW I T H IS T HE PROPER TY OF ALT I U M LI M I TED AN D M AY BE F REELY D IST R IBU TED I N W HOLE. NO R IGH TS ARE RESERVED OR EXPRESS OR I MPLIED WARAN TEE GIVEN . | | REVISI O | N DESC R IPT I O N | DAT E | APPR OVED

REV. SHT. DWG. NO.

T xRx | D _N | X4- 13

Josh Horne Basement Labs LL

DIFF1 | | DIFF1 | 0 0 B | 4 | R1 6 7 5 C1 5 | R1 7 7 5 C1 6

DATE | PRO JECT | **** APPROVALS

ETH Link LED (RJ45 Yellow)

DSN:

JECT REVISION: PRO Not in version control | DOCUMENT REVISION: Not in | DESIGN ITEM : version control

CHK: *

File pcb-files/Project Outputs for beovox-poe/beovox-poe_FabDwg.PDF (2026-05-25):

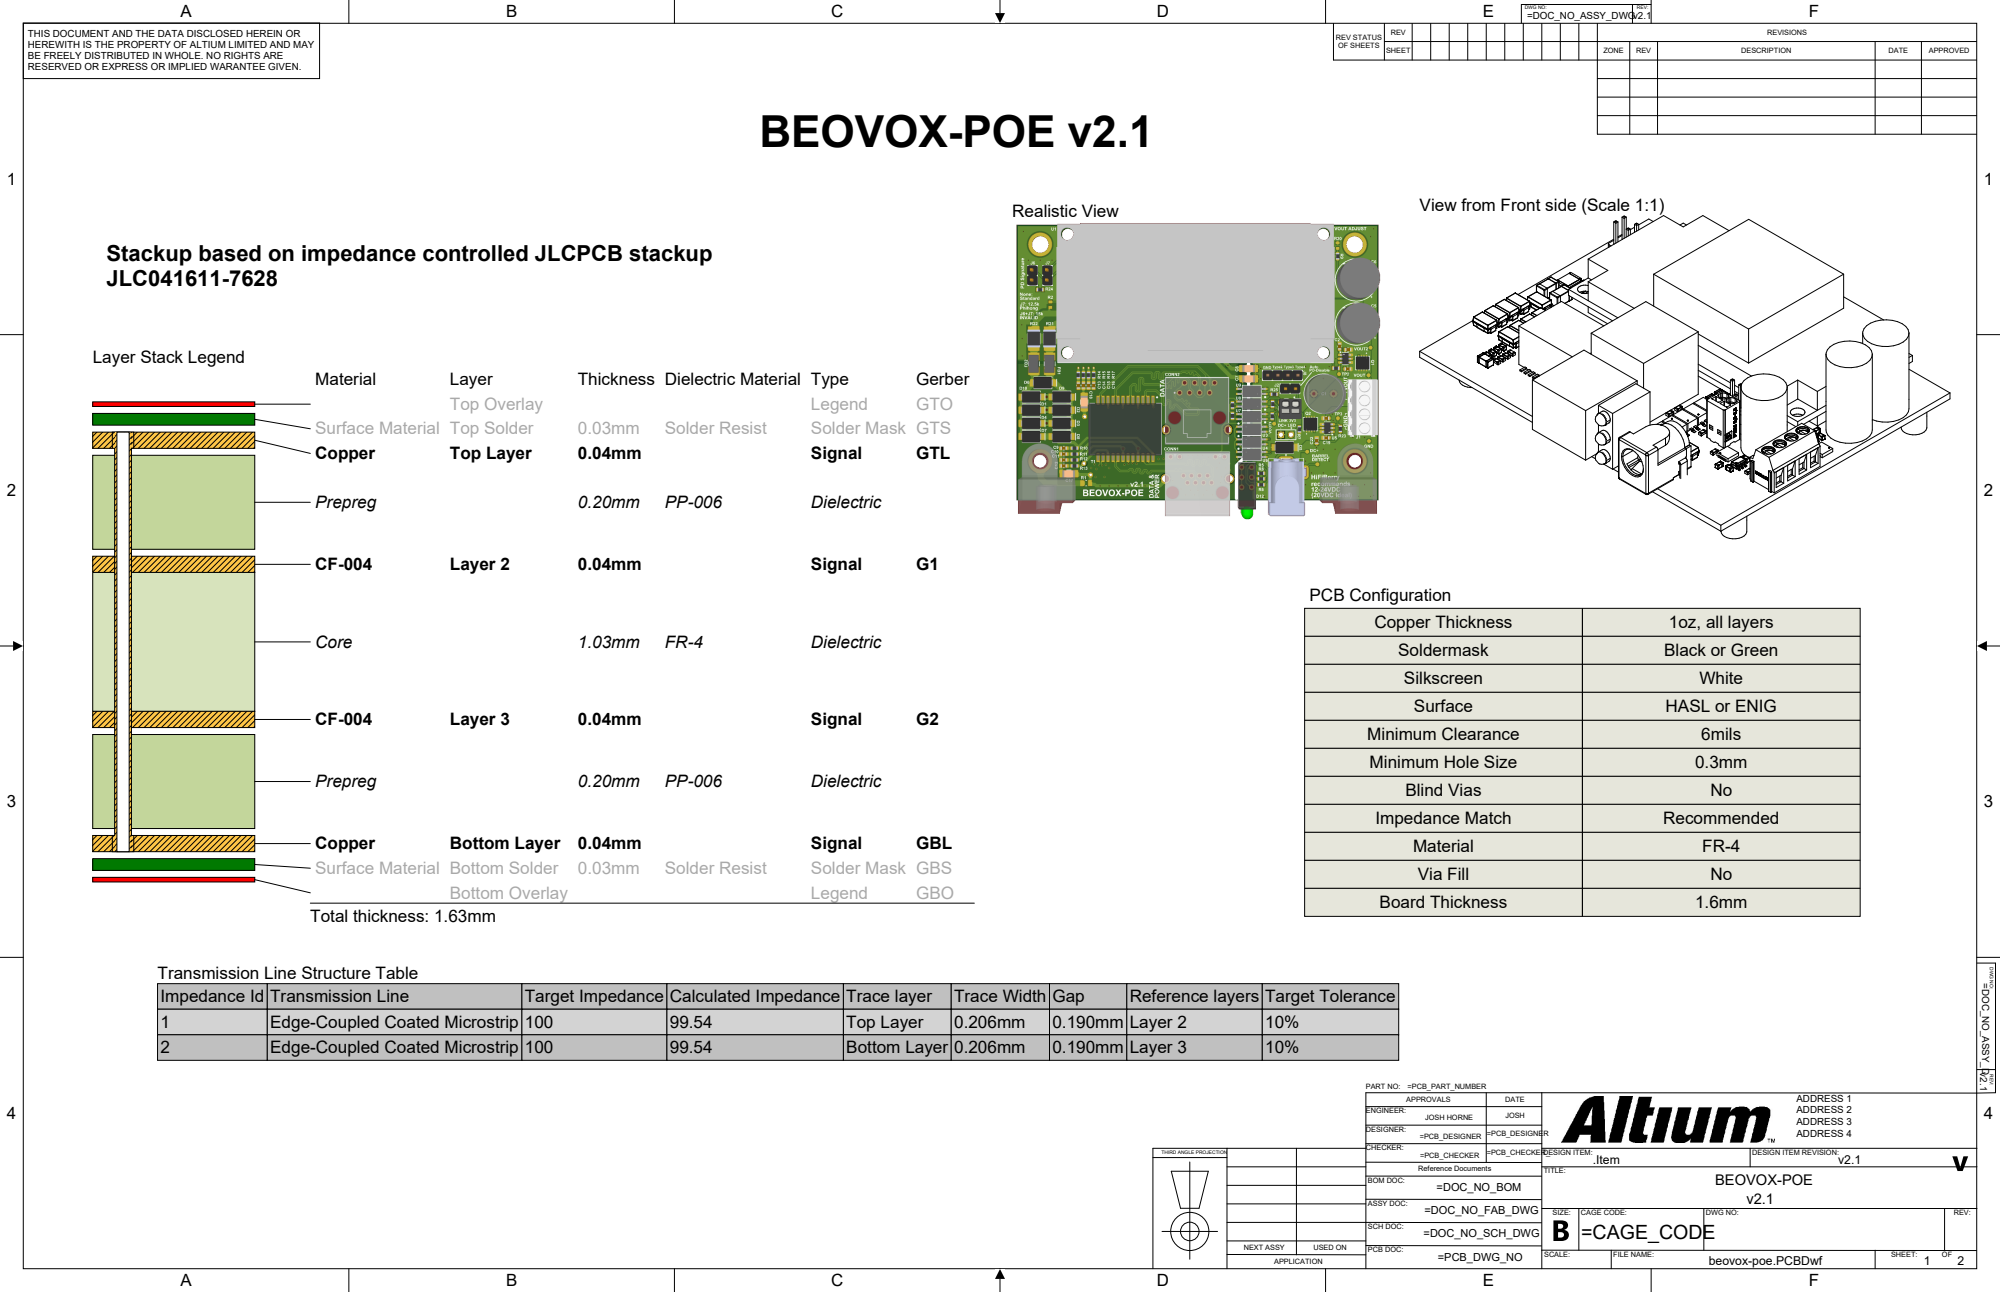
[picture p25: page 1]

HEREWITH IS THE PROPERTY OF ALTIUM LIMITED AND MAY
BE FREELY DISTRIBUTED IN WHOLE. NO RIGHTS ARE
RESERVED OR EXPRESS OR IMPLIED WARANTEE GIVEN.

Stackup based on impedance controlled JLCPCB stackup
JLC041611-7628

Transmission Line
Edge-Coupled Coated Microstrip

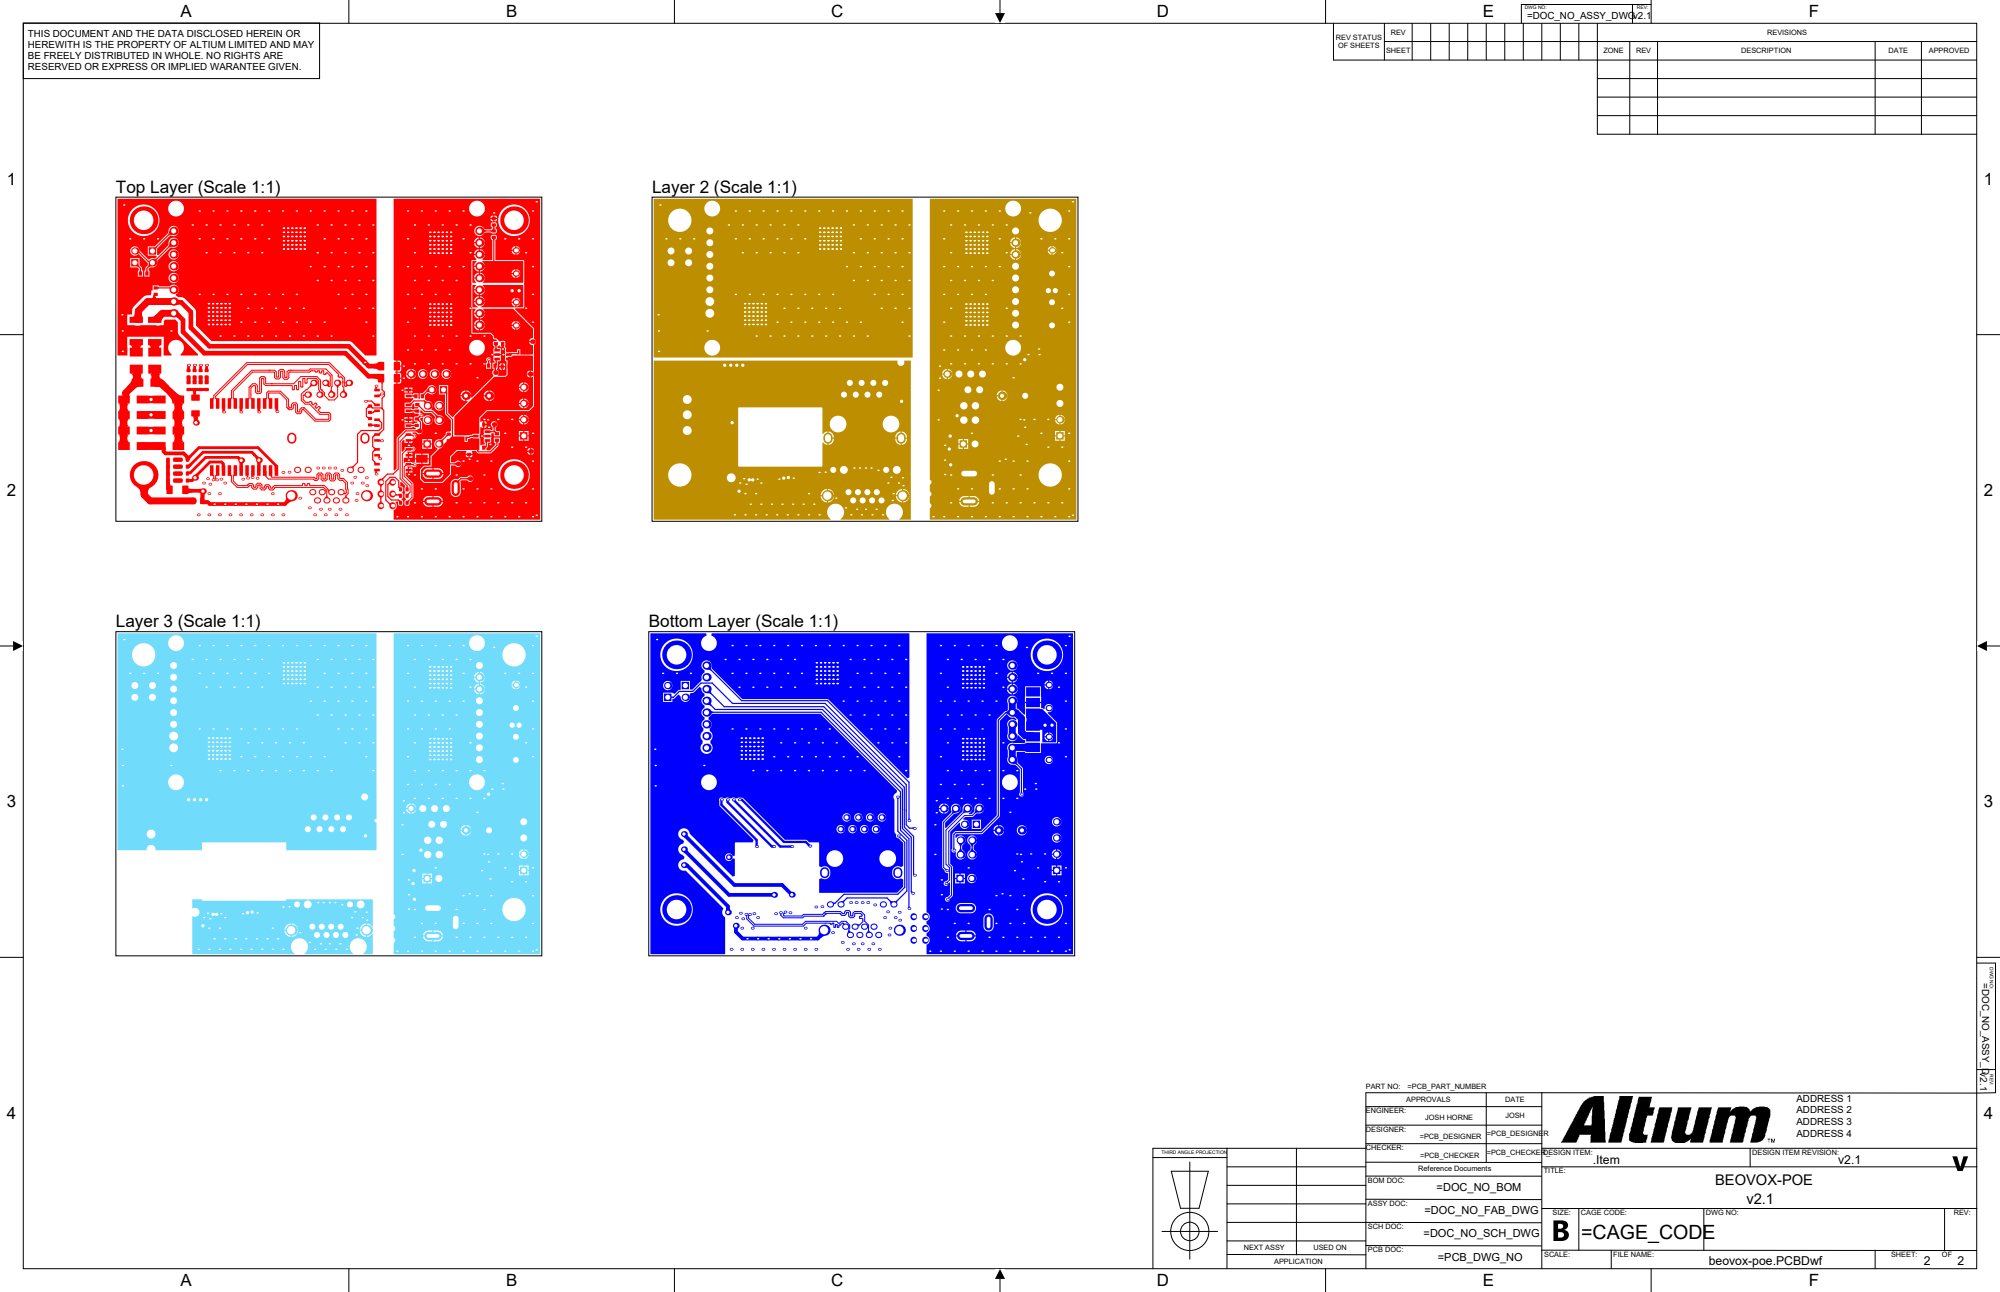
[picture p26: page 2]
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

APPROVALS | DATE

ENGINEER: JOSH HORNE | JOSH

DESIGNER: =PCB_DESIGNER

THIRD ANGLE PROJECTION

CHECKER: =PCB_CHECKER | =PCB_CHECKER_

SCH DOC: =DOC_NO_SCH_DWG

NEXT ASSY | USED ON

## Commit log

2024-03-18 add readme, create new outputs
    [Bill of Materials-beovox-poe(assembly).csv, Bill of Materials-beovox-poe.csv, Pick Place for beovox-poe(assembly).csv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]
2024-03-18 remove old files, update organization
    [Bill of Materials-beovox-poe(assembly).csv, Bill of Materials-beovox-poe.csv, Pick Place for beovox-poe(assembly).csv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]
2024-03-18 readme in progress, test image link
    [Bill of Materials-beovox-poe.csv, Pick Place for beovox-poe.csv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]
2024-03-18 more readme updates
    [pcb-mount-left.step, pcb-mount-right.step]
2026-04-19 Refresh docs, CAD assets, and PCB outputs
    [Bill of Materials-beovox-poe(assembly).csv, Pick Place for beovox-poe(assembly).csv, beovox-panel-dcled.step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]
2026-04-22 Update README and retire old panel CAD files
    [beovox-panel-mount.f3z, beovox-panel-mount.step, pcb-mount-left.step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]
2026-05-17 Add updated 3D model files
    [CX100-panel-dcled.3mf, CX100-panel-dcled.step, CX100-panel-sub-blank.step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]
2026-05-25 Update PCB files to v2.1
    [Bill of Materials-beovox-poe(assembly).csv, Pick Place for beovox-poe(assembly).csv, beovox-poe(assembly).step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]
2026-05-26 update pcb images. add assembly video link
